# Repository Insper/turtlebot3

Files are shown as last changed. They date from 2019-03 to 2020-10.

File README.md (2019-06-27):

# Menu_troca_rede:

- Conecta automaticamente em uma rede pré-selecionada com maior prioridade
- Mostra nome da Rede + IP atualmente conectada
- Lista redes disponiveis para conexão
- Conecta em uma rede selecionada na lista
- Desliga a Raspberry

# Bumper:

- Sensor fim de curso integrado ao ROS via Raspberry

Trocando de Rede
https://www.youtube.com/watch?v=bGi5jZc8NPE&feature=youtu.be

Desligando o Robô
https://www.youtube.com/watch?v=MMxhFo8dfZQ&feature=youtu.be

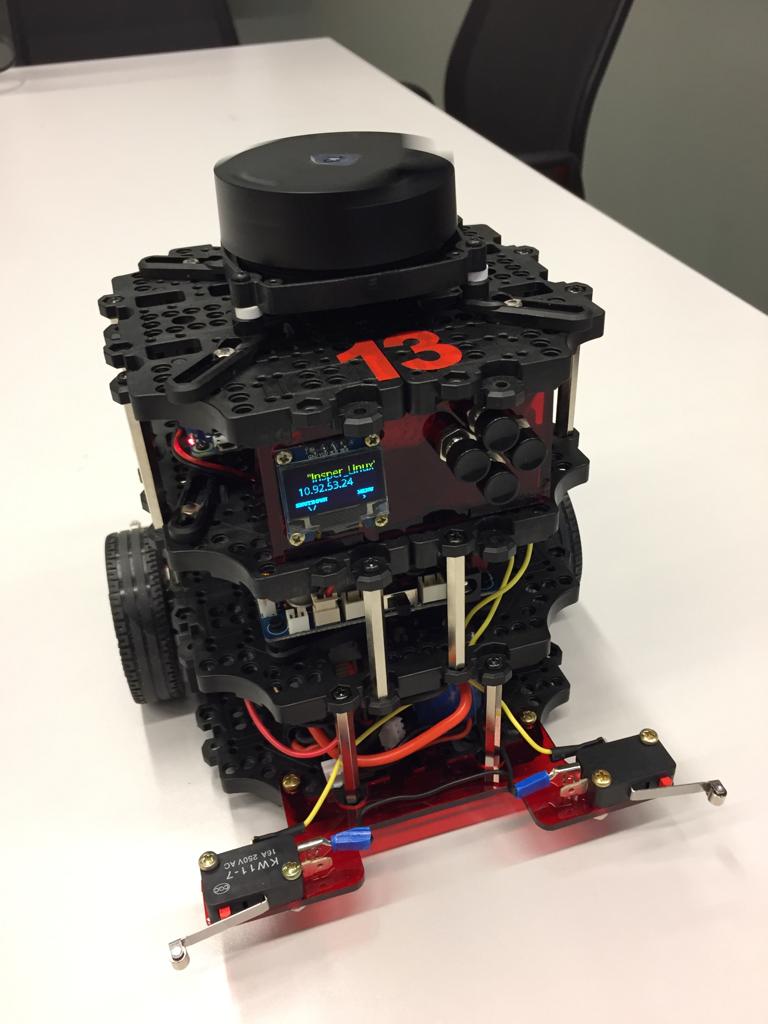
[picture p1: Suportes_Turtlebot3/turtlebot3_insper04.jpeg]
TURTLEBOT3


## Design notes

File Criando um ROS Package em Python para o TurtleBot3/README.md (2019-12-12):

# Criando um ROS Package em python para o Turtlebot3. 

## Objetivo

Queremos ao final desse tutorial ter uma forma de controlar o ângulo da câmera do nosso robô TurtleBot3 através do ROS. Como faremos isso? Simples! Vamos criar o nosso própio ROS package.

## Preparações

Se estiver utilizando o robô TurtleBot3 da matéria de robótica, pule para parte Criando o ROS Package. 

Caso contrário, execute os passos abaixo.

Abra um terminal (Crtl+Alt+T) e execute os comando abaixo:

Instalando alguns pacotes e bibliotecas para ter acesso aos pinos (GPIO) da Raspberry do robô.
 
```bash
  sudo apt update
  sudo apt install python-dev python-pip python-setuptools
  pip install RPi.GPIO
```      

Criando um novo Workspace, caso tenha instalado o ROS e ainda não tenha criado nenhum ainda.
```
  mkdir ~/catkin_ws/src
  cd ~/catkin_ws/src
  catkin_init_workspace
```

## Criando o ROS Packgage

Agora vamos criar o ROS packgage, o nome será "servo_camera" e terá 3 dependências, são elas:

    rospy = para conectar o Python ao ROS
    std_msgs = Wrappers(invólucro) padrão para os tipos primitivos de mensagem ROS (String, Int, Char, Byte...) 
    python-rpi.gpio = para acessar os pinos(GPIO)

No terminal execute os comandos:

```
    cd ~/catkin_ws/src
    catkin_create_pkg servo_camera rospy std_msgs -s python-rpi.gpio
```
Pronto! Package criado com sucesso, no terminal vamos observar:

```
    insper@robo:~/catkin_ws/src$ catkin_create_pkg servo_camera rospy std_msgs -s python-rpi.gpio
    Created file servo_camera/CMakeLists.txt
    Created file servo_camera/package.xml
    Created folder servo_camera/src
    Successfully created files in /home/engecorp/catkin_ws/src/servo_camera. Please adjust the values in package.xml.
```
## Escrevendo o ROS node

A câmera do nosso robo está conecta em um servo motor, logo, temos que escrever um Script Python que recebe comandos publicados em ROS e converte em um sinal PWM que determina a posição do servo motor.

No terminal, crie dentro da pasta /src um novo arquivo Python executável:

```
    cd servo_camera/src/
    touch driver_node
    chmod a+x driver_node
```

Abra o script Python com o editor da sua preferência:

```bash
    nano driver_node
```

Cole o código abaixo:

```python
#!/usr/bin/env python

# Importa as bibliotecas do ROS e do Python
import rospy
from std_msgs.msg import String, Float32

import RPi.GPIO as GPIO
import time as time

# Seta o modo do  GPIO
GPIO.setmode(GPIO.BCM)
GPIO.setwarnings(False)

# Seta o GPIO do servo motor
pinMotorAForwards = 18

# Seta a frequencia
Frequency = 50
# Seta o DutyCycle
DutyCycle = 8
DutyCycle2 =5
# Para o servo motor
Stop = 0

# Seta o pino do servo motor como saida
GPIO.setup(pinMotorAForwards, GPIO.OUT)

# Ajusta a frequencia do PWM
pwmMotor = GPIO.PWM(pinMotorAForwards, Frequency)

# Inicializa o PWM (servo parado)
pwmMotor.start(Stop)

# Funcao stop servo motor
def StopMotor():
    pwmMotor.ChangeDutyCycle(Stop)

# Funcao sobe camera
def SobeCamera():
    pwmMotor.ChangeDutyCycle(DutyCycle)

# Funcao desce camera
def DesceCamera():
    pwmMotor.ChangeDutyCycle(DutyCycle2)

# Funcao posicao
def PosCamera(command):
    pwmMotor.ChangeDutyCycle(command)

# Funcao Callback (le o comando recebido)
def CommandCallback(commandMessage):
    command = commandMessage.data
    if command == 'sobe':
        print('sobe Camera')
        SobeCamera()
        time.sleep(0.5)
        StopMotor()
        time.sleep(0.5)

    elif command == 'desce':
        print('Desce Camera')
        DesceCamera()
        time.sleep(0.5)
        StopMotor()
        time.sleep(0.5)

    elif command == 'stop':
        print('Parando')
        StopMotor()
    else:
        print('Posicao', command)
        PosCamera(command)
        time.sleep(0.5)
        StopMotor()
        time.sleep(0.5)

# Incia o node 
rospy.init_node('driver')

rospy.Subscriber('servo_camera/position', Float32, CommandCallback)
rospy.Subscriber('servo_camera/command', String, CommandCallback)

rospy.spin()
print('Shutting down: stopping motors')
StopMotor()
```

Salve e feche o arquivo.

## Compilando o Workspace com o nosso package:

Para finalizar a criação do nosso package, vamos compilar o Workspace no /catkin_ws, vale resaltar que deve ser compilado na raiz do Workspace. No terminal execute:

```
    cd ~/catkin_ws
    catkin_make
```

Se a compilação chegou em 100%, tudo ocorreu corretamente. O terminal irá indicar algo parecido: 

```bash
insper@robo:~/catkin_ws $ catkin_make
Base path: /home/pi/catkin_ws
Source space: /home/pi/catkin_ws/src
Build space: /home/pi/catkin_ws/build
Devel space: /home/pi/catkin_ws/devel
Install space: /home/pi/catkin_ws/install
####
#### Running command: "make cmake_check_build_system" in "/home/pi/catkin_ws/build"
####
####
#### Running command: "make -j4 -l4" in "/home/pi/catkin_ws/build"
####
[  0%] Built target sensor_msgs_generate_messages_py
[  0%] Built target std_msgs_generate_messages_py
[  0%] Built target _turtlebot3_msgs_generate_messages_check_deps_Sound
[  0%] Built target _turtlebot3_msgs_generate_messages_check_deps_VersionInfo
[  0%] Built target _turtlebot3_msgs_generate_messages_check_deps_PanoramaImg
[  0%] Built target _turtlebot3_msgs_generate_messages_check_deps_SetFollowState
[  0%] Built target _turtlebot3_msgs_generate_messages_check_deps_SensorState
[  0%] Built target std_msgs_generate_messages_nodejs
[  0%] Built target sensor_msgs_generate_messages_nodejs
[  0%] Built target _turtlebot3_msgs_generate_messages_check_deps_TakePanorama
[  0%] Built target std_msgs_generate_messages_lisp
[  0%] Built target sensor_msgs_generate_messages_lisp
[  0%] Built target std_msgs_generate_messages_eus
[  0%] Built target sensor_msgs_generate_messages_eus
[  0%] Built target sensor_msgs_generate_messages_cpp
[  0%] Built target std_msgs_generate_messages_cpp
[  0%] Built target rosgraph_msgs_generate_messages_lisp
[  0%] Built target roscpp_generate_messages_nodejs
[  0%] Built target roscpp_generate_messages_lisp
[  0%] Built target roscpp_generate_messages_eus
[  0%] Built target roscpp_generate_messages_cpp
[  0%] Built target roscpp_generate_messages_py
[  0%] Built target rosgraph_msgs_generate_messages_nodejs
[  0%] Built target rosgraph_msgs_generate_messages_py
[  0%] Built target rosgraph_msgs_generate_messages_cpp
[  0%] Built target rosgraph_msgs_generate_messages_eus
[  2%] Built target raspicam_node_gencfg
[  6%] Built target raspicamcontrol
[ 10%] Built target raspicli
[ 10%] Built target diagnostic_msgs_generate_messages_lisp
[ 10%] Built target geometry_msgs_generate_messages_eus
[ 10%] Built target geometry_msgs_generate_messages_cpp
[ 10%] Built target geometry_msgs_generate_messages_lisp
[ 10%] Built target geometry_msgs_generate_messages_nodejs
[ 10%] Built target geometry_msgs_generate_messages_py
[ 10%] Built target diagnostic_msgs_generate_messages_nodejs
[ 10%] Built target diagnostic_msgs_generate_messages_cpp
[ 10%] Built target diagnostic_msgs_generate_messages_py
[ 10%] Built target diagnostic_msgs_generate_messages_eus
[ 28%] Built target turtlebot3_msgs_generate_messages_py
[ 41%] Built target turtlebot3_msgs_generate_messages_nodejs
[ 54%] Built target turtlebot3_msgs_generate_messages_lisp
[ 69%] Built target turtlebot3_msgs_generate_messages_eus
[ 82%] Built target turtlebot3_msgs_generate_messages_cpp
[ 86%] Built target hlds_laser_segment_publisher
[ 91%] Built target hlds_laser_publisher
[ 91%] Built target turtlebot3_msgs_generate_messages
[ 95%] Built target raspicam_node
[100%] Built target turtlebot3_diagnostics
```

Parabéns! Criamos nosso ROS packgage em Python que controla o ângulo da câmera do nosso robô TurtleBot3. 

## Executando

Para utilizar temos que rodar o node criado, no terminal do robo:

```
    rosrun servo_camera driver_node
```

Do PC remoto (PC que se conecta ao robô), podemos visualizar os 2 tópicos, execute no terminal:

```
    Roscore
```

Abra um novo terminal, não cancele a operação do primeiro terminal, rode:

```
    rostopic list
```

Dentre os topicos listados, temos os 2 topicos que criamos:

```
    /servo_camera/command
    /servo_camera/position
```

Para publicar um comando rode:

```
    rostopic pub -1 servo_camera/command std_msgs/String "sobe"
    rostopic pub -1 servo_camera/command std_msgs/String "desce"
```
    
ou 

```    
    rostopic pub -1 servo_camera/position std_msgs/Float32 6
```
*** Observacao *** Existe uma limitação física na montagem da camera que restringe a variação do ângulo da câmera entre os valores 4 e 11.

## Ligação do Servo Motor na Raspberry Py 

A ligação do servo motor é bem simples e pode ser vista na imagem abaixo:

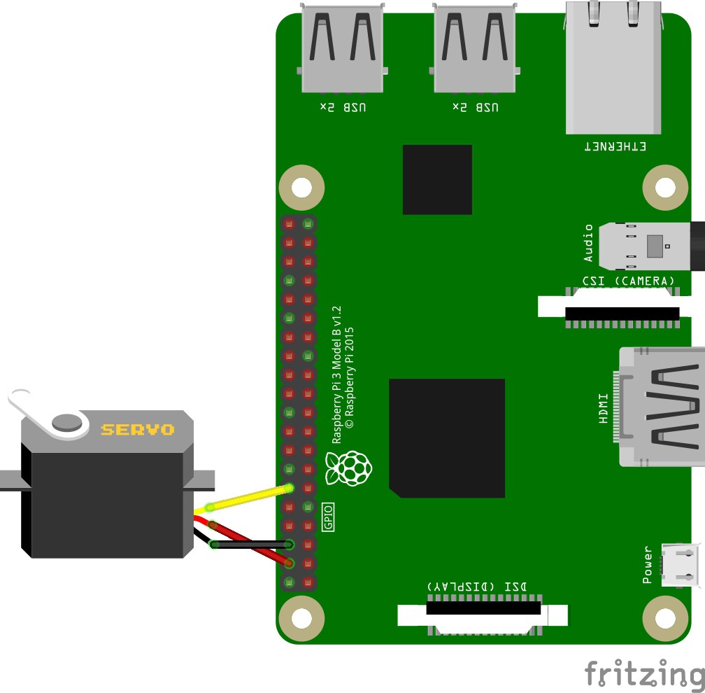
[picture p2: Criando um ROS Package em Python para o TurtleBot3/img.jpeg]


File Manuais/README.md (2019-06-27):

# Documentação de procedimentos e Manuais do TurtleBot3

[Procedimentos para manutenção do Turtlebot 3 Burger ](https://drive.google.com/drive/folders/1hfYtyy-8ZpKP3JPr3eAu3raC31xjLDV2)

[Instrução para integração da OpenCR 1.0 com a  IDE do Arduino ](https://drive.google.com/drive/folders/1QLU0i7zrm9wz8y7pYGHu7u2vuVnl6YnU)

[Manual do Fabricante Turtlebot3 - Burger ](https://drive.google.com/drive/folders/13JiMVwklAkd51lWxJTq1ACc4vhly9uup)

[Script que instala infra de Robotica Computacional no Linux 18.04 (Versão 2019-01)](https://github.com/Insper/404/blob/master/scripts_robotica/infra_robotica.sh)

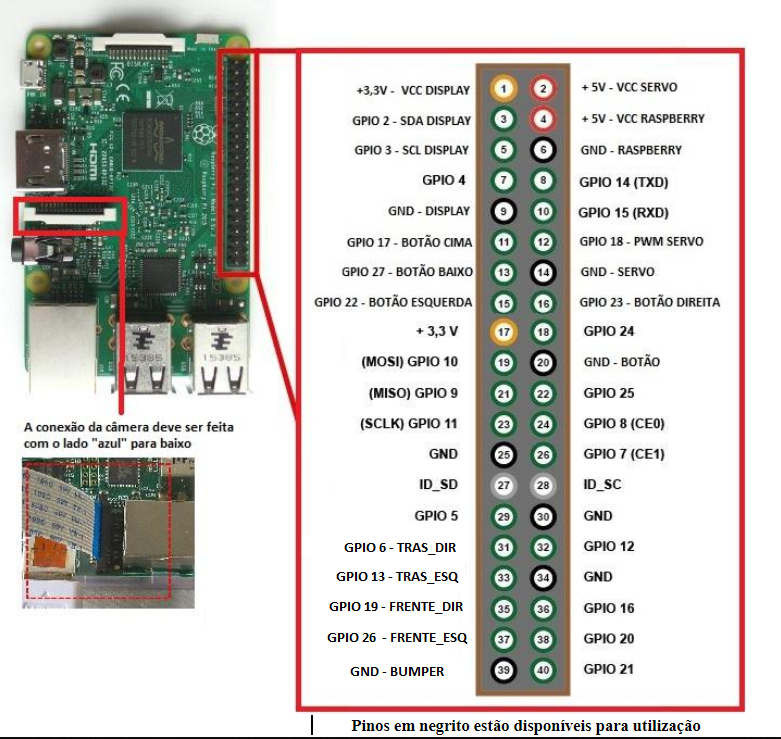
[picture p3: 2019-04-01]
GPIO_TURTLE.png

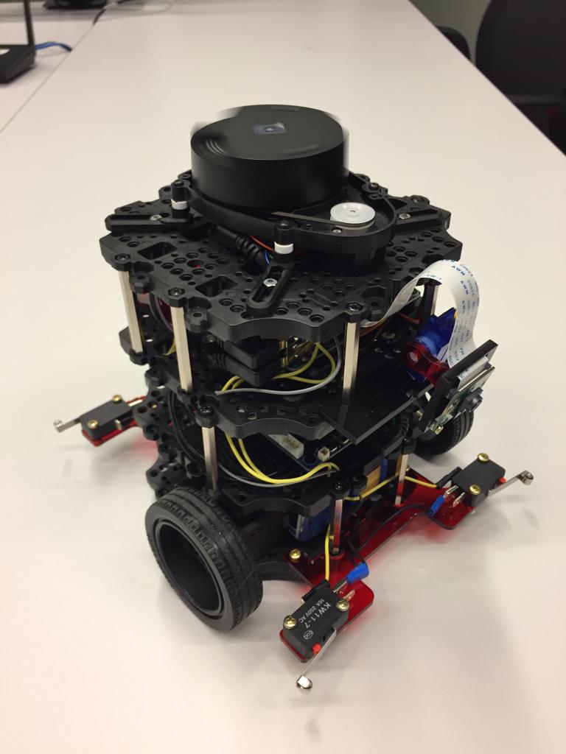
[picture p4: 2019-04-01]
Suportes_Turtlebot3/turtlebot3_insper05.jpeg

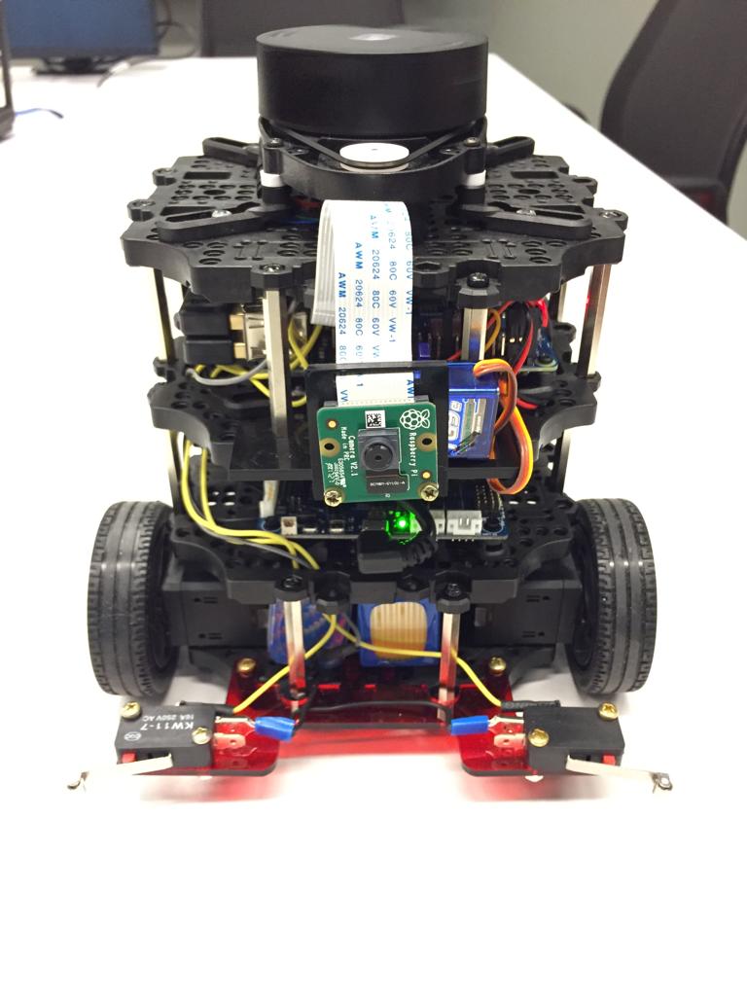
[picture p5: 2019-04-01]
Suportes_Turtlebot3/turtlebot3_insper02.jpeg

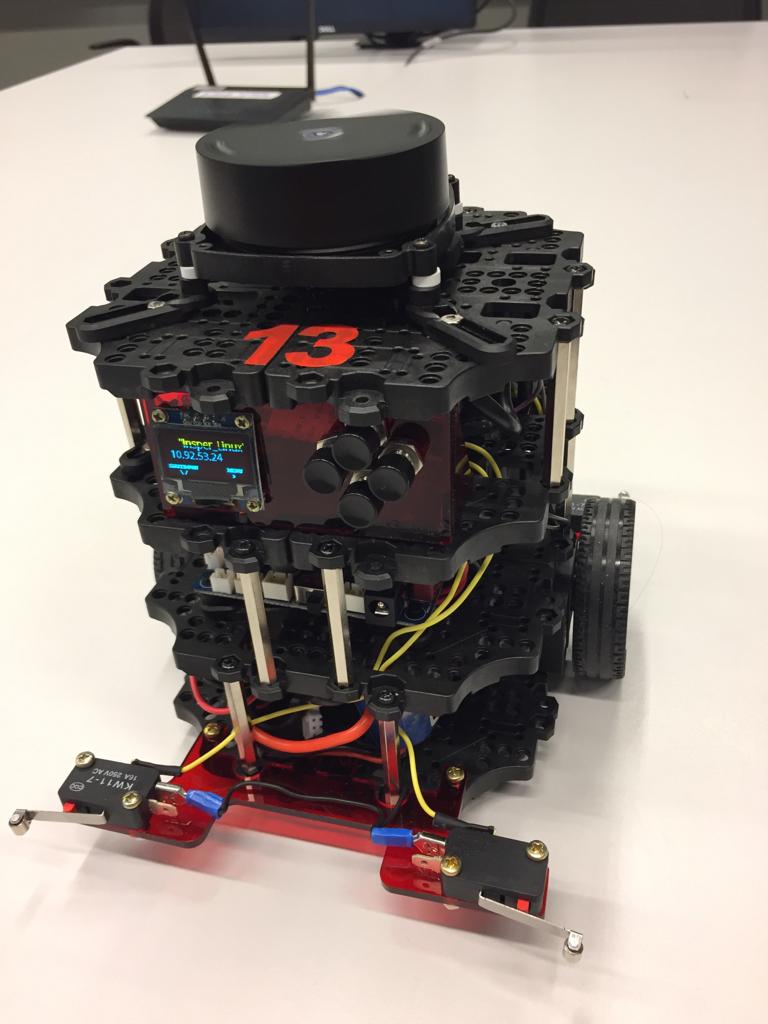
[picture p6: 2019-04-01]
Suportes_Turtlebot3/turtlebot3_insper03.jpeg

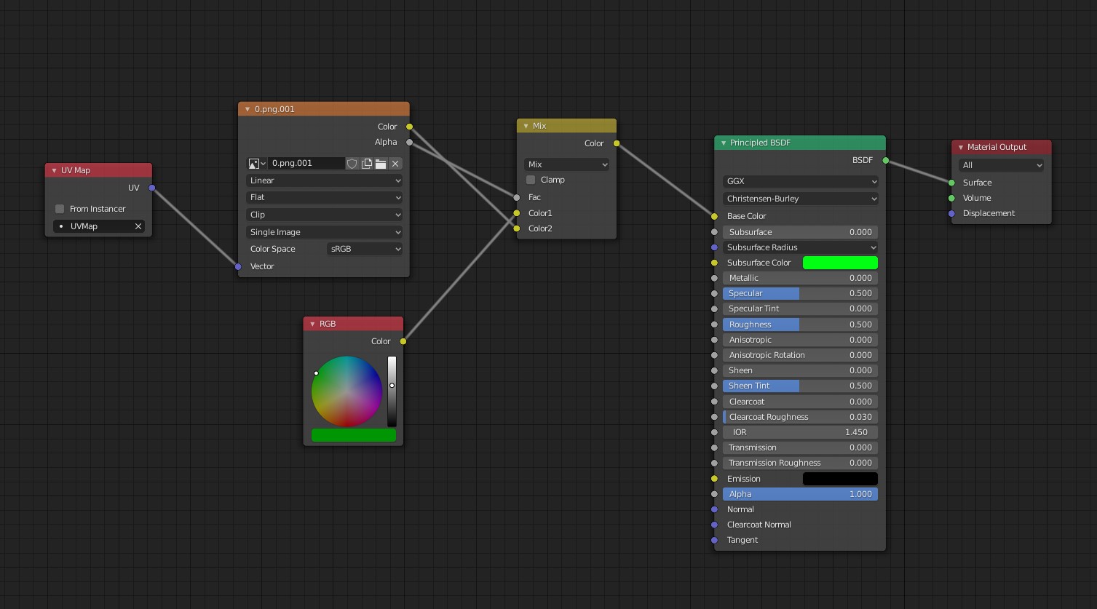
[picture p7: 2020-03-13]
Creeper/Annotation 2020-03-13 114017.jpg

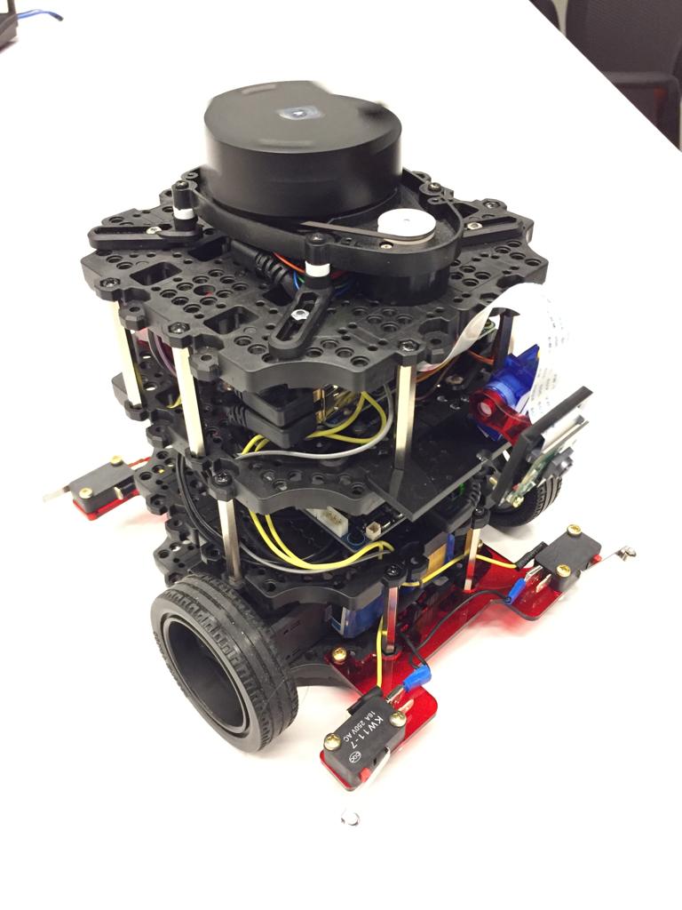
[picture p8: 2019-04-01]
Suportes_Turtlebot3/turtlebot3_insper01.jpeg

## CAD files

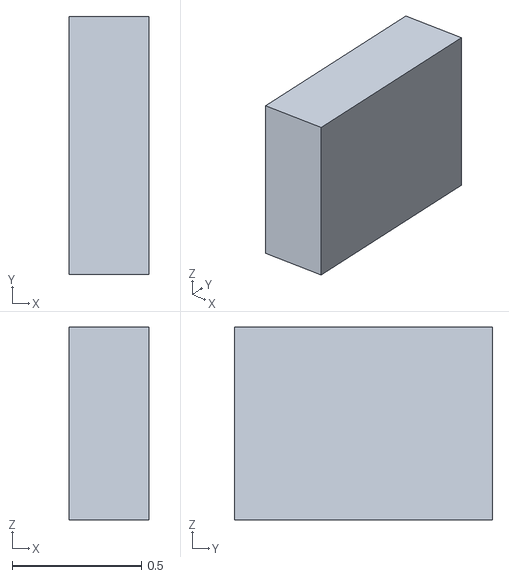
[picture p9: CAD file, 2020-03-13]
Creeper/ID 0.obj
0.31 x 1.00 x 0.748

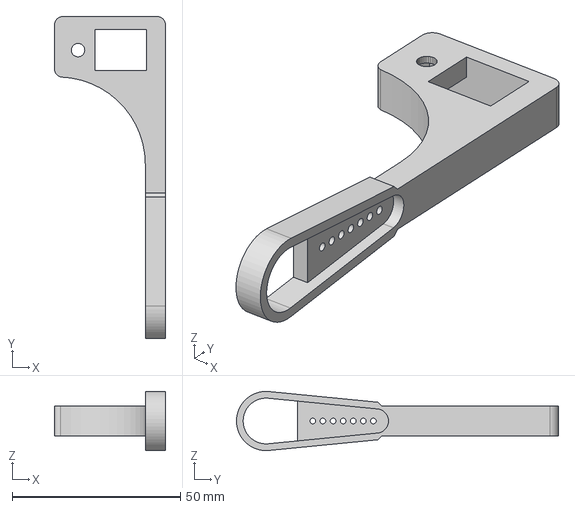
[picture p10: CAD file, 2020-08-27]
Garra/arquivos_solid/garrabraco.step
33.0 x 95.7 x 17.6 mm

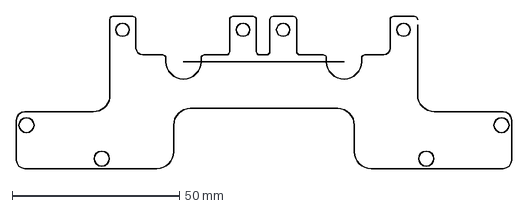
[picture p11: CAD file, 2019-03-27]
Suportes_Turtlebot3/Suporte_Bumper/Suporte_Bumper.dxf
148.0 x 45.5 mm

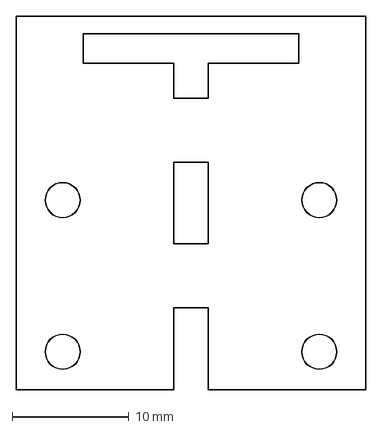
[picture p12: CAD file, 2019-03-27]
Suportes_Turtlebot3/Suporte_Camera_RaspBerry/Suporte_CameraRaspBerry_Face.dxf
30.0 x 32.0 mm

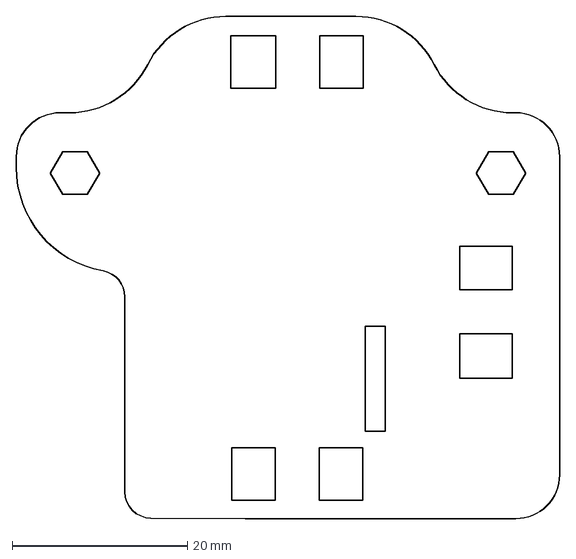
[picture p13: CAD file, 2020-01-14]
Suportes_Turtlebot3/Suporte_Garra/Base.dxf
62.0 x 57.3 mm

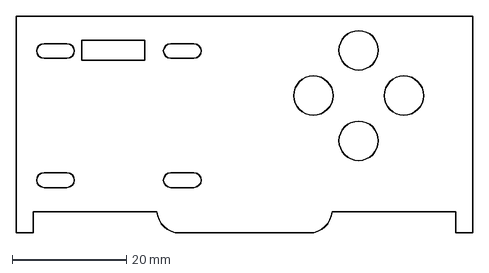
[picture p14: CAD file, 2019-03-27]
Suportes_Turtlebot3/Suporte_OLED _ Botoes/Base_OLED_botoes.dxf
80.0 x 38.0 mm

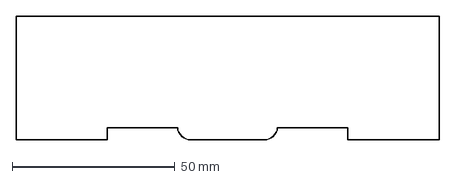
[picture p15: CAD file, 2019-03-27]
Suportes_Turtlebot3/Suporte_RealSense/Suporte_RealSense_Face.dxf
130.0 x 38.0 mm

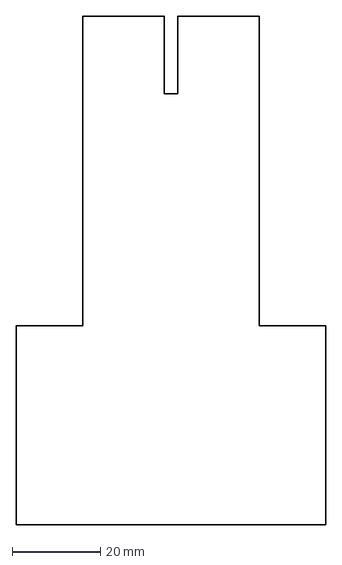
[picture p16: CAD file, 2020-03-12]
Creeper/2 - Creeper.dxf
70.0 x 115.0 mm

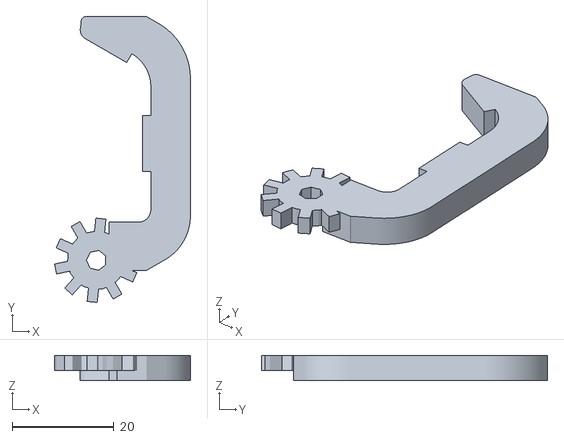
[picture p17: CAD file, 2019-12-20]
Garra/garra-esquerda.stl
26.8 x 56.3 x 5.00

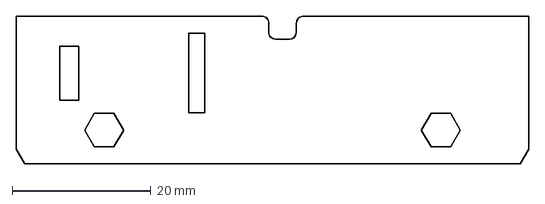
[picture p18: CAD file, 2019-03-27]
Suportes_Turtlebot3/Suporte_Camera_RaspBerry/Base_Camera.dxf
74.0 x 21.3 mm

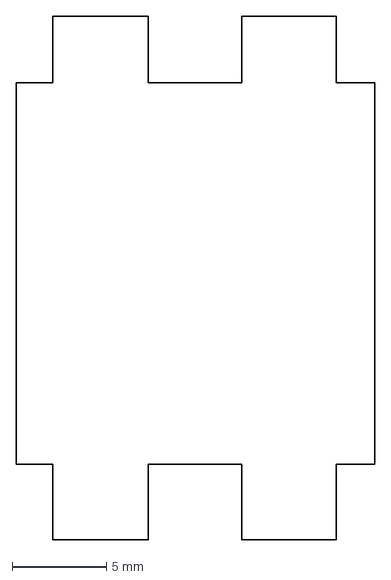
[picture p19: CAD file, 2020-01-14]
Suportes_Turtlebot3/Suporte_Garra/lateral.dxf
19.0 x 27.7 mm

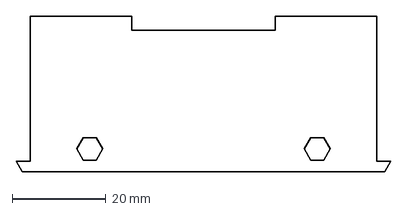
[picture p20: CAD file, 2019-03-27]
Suportes_Turtlebot3/Suporte_OLED _ Botoes/Base_OLED.dxf
80.0 x 33.2 mm

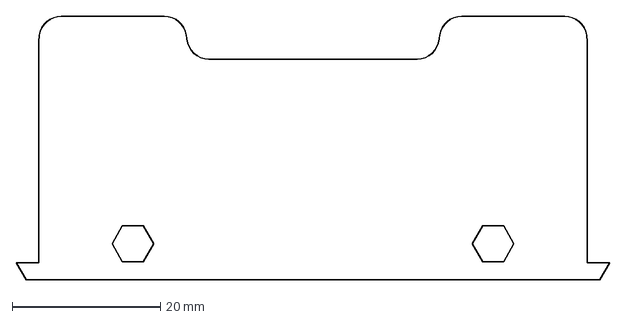
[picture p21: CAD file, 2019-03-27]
Suportes_Turtlebot3/Suporte_RealSense/Suporte_RealSense_Base.dxf
80.0 x 35.5 mm

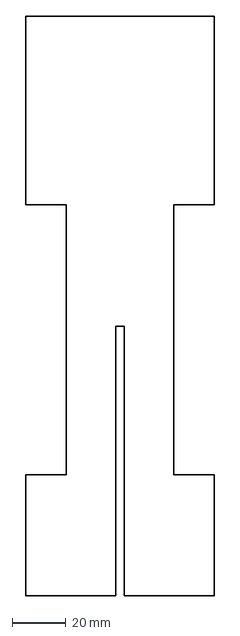
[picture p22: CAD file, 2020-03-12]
Creeper/1 - Creeper.dxf
70.0 x 215.0 mm

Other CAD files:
Garra/garrabraco.stl
Garra/garra-direita.stl
Suportes_Turtlebot3/Suporte_Camera_RaspBerry/Suporte_servo_camera.dxf
Suportes_Turtlebot3/Suporte_Garra/SuporteGarra-P1update.stl
Creeper/Creeper - Montagem.f3z
Creeper/Creeper.blend
Garra/arquivos_solid/garrabraco.obj
Garra/garra-braco.stl
Garra/garrabraco-REBAIXO.stl
Garra/garradireita.stl
Garra/garraesquerda.stl
Suportes_Turtlebot3/Suporte_Garra/SuporteGarra-P1.stl
Suportes_Turtlebot3/Suporte_Garra/SuporteGarra-P2.stl
Suportes_Turtlebot3/Suporte_OLED _ Botoes/Suporte_Lateral_OLED.dxf
Suportes_Turtlebot3/Suporte_RealSense/Suporte_RealSense_Lateral.dxf

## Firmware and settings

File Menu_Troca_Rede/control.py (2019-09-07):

#!/usr/bin/python
# -*- coding: latin-1 -*-
import os, sys
import math
import time
import Adafruit_GPIO.SPI as SPI
import Adafruit_SSD1306
from PIL import Image
from PIL import ImageFont
from PIL import ImageDraw
import subprocess
import RPi.GPIO as GPIO


gpio_pin_down = 27
gpio_pin_up = 17
gpio_pin_left = 22
gpio_pin_right = 23


# Botao
GPIO.setmode(GPIO.BCM)
GPIO.setup(gpio_pin_down, GPIO.IN, pull_up_down=GPIO.PUD_UP)
GPIO.setup(gpio_pin_up, GPIO.IN, pull_up_down=GPIO.PUD_UP)
GPIO.setup(gpio_pin_left, GPIO.IN, pull_up_down=GPIO.PUD_UP)
GPIO.setup(gpio_pin_right, GPIO.IN, pull_up_down=GPIO.PUD_UP)



# Load default font.
#font = ImageFont.load_default()
uma=6
font_small = ImageFont.truetype('/home/pi/fonts/OpenSans-Regular.ttf', 16)
font = ImageFont.truetype('/home/pi/fonts/OpenSans-ExtraBoldItalic.ttf', 14)
font14 = ImageFont.truetype('/home/pi/fonts/OpenSans-Regular.ttf', 16)
menu=0
endereco = "ERROR"
rede = "nao conectada"
p1=2
p2=2
p3=2
p4=2
linha1="     oi"
linha2="     oi"
linha3="     oi"
linha4="     oi"
font1=font
font2=font
font3=font
font4=font
global lista_rede
global Asimov
global flu
global fl
Asimov=None
fl=1 
flu=1
# Raspberry Pi pin configuration:
RST = 24
# Note the following are only used with SPI:
DC = 23
SPI_PORT = 0
SPI_DEVICE = 0

# 128x64 display with hardware I2C:
disp = Adafruit_SSD1306.SSD1306_128_64(rst=RST)

# Initialize library.
disp.begin()

# Get display width and height.
width = disp.width
height = disp.height

# Clear display.
disp.clear()
disp.display()

# Create image buffer.
# Make sure to create image with mode '1' for 1-bit color.
image = Image.new('1', (width, height))
# First define some constants to allow easy resizing of shapes.
padding = 2
shape_width = 20
top = padding
emy=top
bottom = height-padding
# Move left to right keeping track of the current x position for drawing shapes.
x = padding
# Load default font.
font = ImageFont.load_default()

# Create drawing object.
draw = ImageDraw.Draw(image)
names = ['Insper_linux','asimov1', 'asimov2', 'asimov3', 'asimov4', 'asimov5', 'asimov6', 'asimov7', 'asimov8', 'asimov9', 'asimov10', 'asimov11','asimov12']

def menu_up(channel):
	#teste para parar de andar 
        os.system("rostopic pub -1 /cmd_vel geometry_msgs/Twist -- '[0.0, 0.0, 0.0]' '[0.0, 0.0, 0.0]'")        
        if menu==10:
		global flag
                global Asimov
              
                if flag in range(0,12):
                        Asimov=names[flag]
                        flag+=1
		else:
			flag=0
			Asimov=names[flag]
        else:
                return
        return(Asimov)
        

def menu_down(channel):
	global menu
	
        if menu==0:
		draw.rectangle((0,0,width,height), outline=0, fill=0)
                draw.text((x, 0),"        Press         ",font=font14,fill=255)
                draw.text((x,20),"   \/ to confirm     ",font=font14,fill=255)
		draw.text((x, 40),"  <  to return    ",font=font14,fill=255)
		menu=1
	elif menu==1:
		uma=5
		while uma!=0:
			uma-=1
			try:
				draw.rectangle((0,0,width,height), outline=0, fill=0)
                		draw.text((x,2),"     SHUTDOWN    ",font=font14,fill=255)
				draw.text((x,25),"             IN {}...   ".format(uma),font=font14,fill=255)
                		time.sleep(1)
			except:
				desliga_robo()            	
		desliga_robo()
        if menu==10:
                global Asimov
		global flag
	#	print(flag)
	
                if flag in range(1,13):
			Asimov=names[flag-1]
                        flag-=1
		else:
			flag=12
			Asimov=names[flag-1]
        return(Asimov)                        
                                        
        
                
        

def menu_left(channel):
        global menu
        menu=0
        
        return
 
def menu_right(channel):
        global menu
        global flag
        
        if menu ==0:
                flag=0
                menu=10
        elif menu ==10:
                menu=20
                
        elif menu ==20:
                menu=0

        else:
                return
        return



def troca_rede():
        global ip_asimov
        try:
	#	print(Asimov)
                sucesso="/home/pi/net/scripts/{}.sh".format(Asimov)
                sucesso=subprocess.check_output([sucesso])
                flu=1
        except:
                time.sleep(1)
def limpa_tela():
        # Draw the image buffer.
        disp.image(image)
        disp.display()
        time.sleep(0.5)
        return

def desliga_robo():
        draw.rectangle((0,0,width,height), outline=0, fill=0)
        global menu
        menu=-12
        time.sleep(1)
        retorno = subprocess.check_output(["sudo","halt"])
       
        return
        
        
def escreveTela(p1,p2,p3,p4,linha1,linha2,linha3,linha4,font1,font2,font3,font4):
        try:
                draw.text((x+23, p1),linha1,font=font1,fill=255)
                draw.text((x+6, p2),linha2,font=font2,fill=255)
                draw.text((x, p3),linha3,font=font3,fill=255)
                draw.text((x, p4),linha4,font=font4,fill=255)

        except:
                draw.rectangle((0,0,width,height), outline=0, fill=0)

        return




GPIO.add_event_detect(gpio_pin_up, GPIO.FALLING, callback = menu_up,bouncetime=300)
GPIO.add_event_detect(gpio_pin_down, GPIO.FALLING, callback = menu_down,bouncetime=300)
GPIO.add_event_detect(gpio_pin_left, GPIO.FALLING, callback = menu_left,bouncetime=300)
GPIO.add_event_detect(gpio_pin_right, GPIO.FALLING, callback = menu_right,bouncetime=300)



while True:
        global lista_rede
        #global Asimov
        #global flu
        global f
        
        limpa_tela()
        
        if menu == 0:
                if flu ==0:
		#	print("troca de rede")
                        troca_rede()
                        flu=1
                try:
		#	print("primeira tela")
                        f=0
                        ip_asimov=subprocess.check_output(["/home/pi/net/scripts/ipendereco.sh"])
                        ip_asimov=ip_asimov.split()
                        rede=ip_asimov[0]
			Asimov=ip_asimov[0]
                        endereco=ip_asimov[1]
                        p1=top
                        p2=top+18
                        p3=45
                        p4=55
                        linha1=rede
                        linha2=endereco
                        linha3="SHUTDOWN        MENU  "
                        linha4="   \/            >"
                        font1=font14
                        font2=font14
                        font3=font
                        font4=font
                        draw.rectangle((0,0,width,height), outline=0, fill=0)
                        escreveTela(p1,p2,p3,p4,linha1,linha2,linha3,linha4,font1,font2,font3,font4)
                
                except:
                        menu=0
                        
        if menu == 10:
		global Asimov
		global flag
		Asimov=names[flag]
                draw.rectangle((0,0,width,height), outline=0, fill=0)
                draw.text((x, 2),"13 Signs Found,conect in",font=font,fill=255)
                draw.text((x+25, 20),"{}?".format(Asimov),font=font14,fill=255)
                draw.text((x, 55),"/\|\/ change     ok >",font=font,fill=255)

        if menu == 20:                               
                        
                        flu=0
                        if f ==0:
                                try:
				#	print("oi")
                                        p1=2
                                        p2=20
                                        p3=45
                                        p4=55
                                        linha4="                       "
                                        linha1="CONNECTING IN      "   
                                        linha2="   {} =3".format(Asimov)
                                        linha3="                       "
                                        font1=font
                                        font2=font14
                                        font3=font14
                                        font4=font14
                                        draw.rectangle((0,0,width,height), outline=0, fill=0)
                                        escreveTela(p1,p2,p3,p4,linha1,linha2,linha3,linha4,font1,font2,font3,font4)
                                        f=1

                                except:
                                     #   print("bugou")
                                        flu=0
                                	troca_rede(Asimov,rede,endereco)                                                

                        else:
                                menu=0

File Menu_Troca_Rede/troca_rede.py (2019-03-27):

#!/usr/bin/python
# -*- coding: latin-1 -*-
import os, sys
import math
import time
import Adafruit_GPIO.SPI as SPI
import Adafruit_SSD1306
from PIL import Image
from PIL import ImageFont
from PIL import ImageDraw
import subprocess
import RPi.GPIO as GPIO
from luma.core.render import canvas
from time import sleep
import socket
from luma.oled.device import ssd1306, ssd1325, ssd1331, sh1106
from luma.core.interface.serial import i2c


serial = i2c(port=1, address=0x3C)
device = ssd1306(serial, rotate=0)
global gdraw, gdevice



gpio_pin_down = 27
gpio_pin_up = 17
gpio_pin_left = 22
gpio_pin_right = 23


# Botao
GPIO.setmode(GPIO.BCM)
GPIO.setup(gpio_pin_down, GPIO.IN, pull_up_down=GPIO.PUD_UP)
GPIO.setup(gpio_pin_up, GPIO.IN, pull_up_down=GPIO.PUD_UP)
GPIO.setup(gpio_pin_left, GPIO.IN, pull_up_down=GPIO.PUD_UP)
GPIO.setup(gpio_pin_right, GPIO.IN, pull_up_down=GPIO.PUD_UP)

# Definições das variáveis
endereco = "ERROR"
rede = "nao conectada"
RST = 24
DC = 23
SPI_PORT = 0
SPI_DEVICE = 0
padding = 2
shape_width = 20

# Configuração inicial
disp = Adafruit_SSD1306.SSD1306_128_64(rst=RST)
disp.begin()
disp.clear()
disp.display()
width = disp.width
height = disp.height
image = Image.new('1', (width, height))
top = padding
emy=top
bottom = height-padding
x = padding
font = ImageFont.load_default()
draw = ImageDraw.Draw(image)
ja = 0
flag=0
names = ['asimov1', 'asimov3', 'asimov5', 'asimov7', 'asimov9', 'asimov11','Shutdown']

#fontes
font_small = ImageFont.truetype('/home/pi/fonts/OpenSans-Regular.ttf', 16)
font = ImageFont.truetype('/home/pi/fonts/OpenSans-ExtraBoldItalic.ttf', 14)
font14 = ImageFont.truetype('/home/pi/fonts/OpenSans-Regular.ttf', 16)




def invert(draw,x,y,text):
    font = ImageFont.load_default()
    draw.rectangle((x, y, x+120, y+10), outline=255, fill=255)
    draw.text((x, y), text, font=font, outline=0,fill="black")

# Box and text rendered in portrait mode
def menu(device, draw, menustr,index):
    global menuindex
    font = ImageFont.load_default()
    draw.rectangle(device.bounding_box, outline="white", fill="black")
    for i in range(len(menustr)):
        if(i == index):
            menuindex = i
            invert(draw, 2, i*10, menustr[i])

        else:
            draw.text((2, i*10), menustr[i], font=font, fill=255)

def conecta():
	global ja
	try: 
		print(strval)
		sucesso="/home/pi/net/{}.sh".format(strval)
                sucesso=subprocess.check_output([sucesso])
		print(sucesso)
	finally: 
		ip_asimov=subprocess.check_output(["/home/pi/net/ipendereco.sh"])
		ip_asimov=ip_asimov.split()
		print(ip_asimov)		
		#rede=ip_asimov[0]
		#endereco=ip_asimov[1]
		ja=0

def desliga():
        draw.rectangle((0,0,width,height), outline=0, fill=0)
        global menu
        menu=-12
        time.sleep(1)
        retorno = subprocess.check_output(["sudo","halt"])

def menu_mostra():
	global names
	draw.rectangle((0,0,width,height), outline=0, fill=0)
	menu(device, draw, names,1)
	menu_operation(strval)

def menu_operation(strval):
 
    if ( strval == "Shutdown"):
	global flag
	if flag==0:
		draw.rectangle((0,0,width,height), outline=0, fill=0)
		draw.rectangle(device.bounding_box, outline="white", fill="black")
       		draw.text((20,20), "SHUTDOWN ", font=font14,fill="white")            	
		draw.text((10, 50), "Press V to confirm ", fill="white")

	elif flag==1:
		uma=5	
		while uma!=0:
			uma-=1
			try:
				draw.rectangle((0,0,width,height), outline=0, fill=0)
                		draw.text((x,2),"     SHUTDOWN    ",font=font14,fill=255)
				draw.text((x,25),"             IN {}...   ".format(uma),font=font14,fill=255)
                		time.sleep(1)
			except:
				desliga()            	
		desliga()

    if ( strval == "asimov1"):
	draw.text((0, 26), "Conectando em Asimov1", fill="white")
    	conecta()			
    if ( strval == "asimov3"):
	draw.text((0, 26), "Conectando em Asimov3", fill="white")
	conecta()
    if ( strval == "asimov5"):
	draw.text((0, 26), "Conectando em Asimov5", fill="white")
	conecta()
    if ( strval == "asimov7"):
	draw.text((0, 26), "Conectando em Asimov7", fill="white")
	conecta()
    if ( strval == "asimov9"):
	draw.text((0, 26), "Conectando em Asimov9", fill="white")
	conecta()
    if ( strval == "asimov11"):
	draw.text((0, 26), "Conectando em Asimov11", fill="white")
	conecta()


def menu_left(channel):  
    global counter		
    strval = names[counter]
    menu_mostra()


def menu_right(channel):
	global strval
	strval = names[6]
	print(strval)
	menu_operation(strval)

def menu_up(channel):  
    global counter
    print(counter)
    if counter >1:
        counter -= 1
        print (counter)
        menu(device, draw, names,counter%7)
    

def menu_down(channel):
	global counter
	print(counter)
	global flag
	global strval
	if strval == names[6]:
		flag =1
		menu_operation(strval)
	elif counter<7:
		counter+= 1
        	print (counter)
      		menu(device,draw,names,counter%7)
        

    		
def limpa_tela():
        # Draw the image buffer.
        disp.image(image)
        disp.display()
        time.sleep(0.5)





counter = 0
insubmenu = 0
strval =names[0]


GPIO.add_event_detect(gpio_pin_up, GPIO.FALLING, callback = menu_up,bouncetime=300)
GPIO.add_event_detect(gpio_pin_down, GPIO.FALLING, callback = menu_down,bouncetime=300)
GPIO.add_event_detect(gpio_pin_left, GPIO.FALLING, callback = menu_left,bouncetime=300)
GPIO.add_event_detect(gpio_pin_right, GPIO.FALLING, callback = menu_right,bouncetime=300)


while True:
	limpa_tela()

	if ja==0:
		ip_asimov=subprocess.check_output(["/home/pi/net/ipendereco.sh"])
		ip_asimov=ip_asimov.split()
		rede=ip_asimov[0]
		endereco=ip_asimov[1]
		ja=1
		draw.rectangle(device.bounding_box, outline="white", fill="black")
       		draw.text((40, 20), rede, fill="white")
       		draw.text((20, 30), endereco, fill="white")
       		draw.text((5, 50), "SHUTDOWN        MENU  ", fill="white")

	
		
	

       


GPIO.cleanup()

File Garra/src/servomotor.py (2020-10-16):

#!/usr/bin/env python

# Importa as bibliotecas do ROS e do Python
import rospy
from std_msgs.msg import String, Float64

import RPi.GPIO as GPIO
import time as time

# Seta o modo do  GPIO
GPIO.setmode(GPIO.BCM)
GPIO.setwarnings(False)

# Seta o GPIO do servo motor
pinMotorBraco = 18
pinMotorGarra = 12

# Seta a frequencia
Frequency = 50

# Seta o DutyCycle da posicao da Braco 
# Braco Sobe
BracoSobe = 11 
# Braco no centro
BracoCentro = 5
# Braco recolhida
BracoRecolhe = 3
# garra fechada
GarraFechada = 5
# garra aberta
GarraAberta = 13


# Para o servo motor
Stop = 0

# Seta o pino do servo motor como saida
GPIO.setup(pinMotorBraco, GPIO.OUT)
GPIO.setup(pinMotorGarra, GPIO.OUT)

# Ajusta a frequencia do PWM
pwmMotorBraco = GPIO.PWM(pinMotorBraco, Frequency)
pwmMotorGarra = GPIO.PWM(pinMotorGarra, Frequency)

# Inicializa o PWM (servo parado)
pwmMotorBraco.start(Stop)
pwmMotorGarra.start(Stop)

# Funcao stop servo motor
def StopMotor():
    pwmMotorBraco.ChangeDutyCycle(Stop)
    pwmMotorGarra.ChangeDutyCycle(Stop)

# Funcao sobe Braco
def SobeBraco():
    pwmMotorBraco.ChangeDutyCycle(BracoSobe)

# Funcao Centro Braco
def DesceBraco():
    pwmMotorBraco.ChangeDutyCycle(BracoCentro)

# Funcao recolhe Braco
def RecolheBraco():
    pwmMotorBraco.ChangeDutyCycle(BracoRecolhe)

# Funcao posicao Braco
def PosBraco(command):
    # converte o valor recebido em radianos para entrada do PWM
    commandBraco = 5 + (2*command) + (0,889 * command**2)
    pwmMotorBraco.ChangeDutyCycle(commandBraco)



# Funcao abre Garra
def AbreGarra():
    pwmMotorGarra.ChangeDutyCycle(GarraAberta)

# Funcao fecha Garra
def FechaGarra():
    pwmMotorGarra.ChangeDutyCycle(GarraFechada)

# Funcao posicao Garra
def PosGarra(command):
    # converte o valor recebido em radianos para entrada do PWM
    commandGarra= (-8*command) + 5
    pwmMotorGarra.ChangeDutyCycle(commandGarra)

# Funcao Callback (le o comando recebido para a posicao da Garra)
def CommandCallback(commandMessage):
    command = commandMessage.data
    if command == 'data: -1':
        print('abre a garra ')
        AbreGarra()
        time.sleep(0.5)
        StopMotor()
        time.sleep(0.5)

    elif command == 'data: 0':
        print('fecha a garra')
        FechaGarra()
        time.sleep(0.5)
        StopMotor()
        time.sleep(0.5)

    elif command == 'data: stop':
        print('Parando')
        StopMotor()
    else:
        print('Posicao', command)
        PosGarra(command)
        time.sleep(0.5)
        StopMotor()
        time.sleep(0.5)

# Funcao Callback1 (le o comando recebido para possicao da Braco)
def CommandCallback1(commandMessage):
    command = commandMessage.data
    if command == 'data: 1.5':
        print('sobe o Braco')
        SobeBraco()
        time.sleep(0.5)
        StopMotor()
        time.sleep(0.5)

    elif command == 'data: 0':
        print('Braco em posição')
        DesceBraco()
        time.sleep(0.5)
        StopMotor()
        time.sleep(0.5)

    elif command == 'data: -1.5':
        print('Recolhe o Braco')
        RecolheBraco()
        time.sleep(0.5)
        StopMotor()
        time.sleep(0.5)

    elif command == 'data: stop':
        print('Parando')
        StopMotor()
    else:
        print('Posicao', command)
        PosBraco(command)
        time.sleep(0.5)
        StopMotor()
        time.sleep(0.5)




# Incia o node 
rospy.init_node('driver')

# joint1 = junta do braço
# joint2 = junta da garra
 
#rospy.Subscriber('servo_garra/command', String, CommandCallback)
rospy.Subscriber('/joint2_position_controller/command', Float64, CommandCallback)
#rospy.Subscriber('servo_braco/command', String, CommandCallback1)
rospy.Subscriber('/joint1_position_controller/command', Float64, CommandCallback1)

rospy.spin()
print('Shutting down: stopping motors')
StopMotor()

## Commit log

2019-03-27 Menu Troca rede + dxfs dos suportes
    [Base_Camera.dxf, Base_OLED.dxf, Base_OLED_botoes.dxf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]
2019-04-01 Pinagem Raspberry Turtlebot3
2019-04-01 scripts para atualização automatica
2019-09-05 botao de parada instantanea
2019-12-13 codigo servo braco
2020-03-13 Creeper certo Blender
    [Creeper.blend]
2020-08-25 versao 2020/2
    [garrabraco.stl]
2020-08-27 versão 2 semestre 2020
    [garrabraco.obj, garrabraco.step]
2020-10-16 ajuste servomotor.py
